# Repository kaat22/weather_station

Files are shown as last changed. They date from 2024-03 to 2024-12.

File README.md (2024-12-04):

# Weather Station

## Introduction
The purpose of this project was to make a weather station (Figure 1), which will read and send the measurements to a server.

kuva Figure 1: Weather station

## Objectives
The basic aim was to make a functional weather station, which would send the data to a server, that could then be read from a computer.
Our secondary aim was to make the weather station rechargeable, using a LiFePO4 battery (Figure 2). Using a battery to power the station allows it to work without being connected to a computer or a power outlet.

kuva Figure 2: LiFePO4 battery

## Methods
The microcontroller we used in the project was ESP32-WROOM-32E (Figure 3). The microcontroller has built-in Wi-Fi that allows it to send the data to a server. There are two sensors which measure the temperature, humidity and air pressure.

kuva Figure 3: ESP32-WROOM-32E

## Results
We achieved our primary goal of gathering and transferring data (via Wi-Fi) from the station's sensors to a server, wherefrom it can be viewed through a web browser. We also partially achieved our secondary goal of powering the device with a rechargeable battery, however due to an error in the pcb design phase we were unable to get the recharging feature of the charging circuit functional.

## Refrences
ESP-32WROOM-32E datasheet Source:

esp32-wroom-32e_esp32-wroom-32ue_datasheet_en.pdf ([espressif.com](https://www.espressif.com/en/support/documents/technical-documents))

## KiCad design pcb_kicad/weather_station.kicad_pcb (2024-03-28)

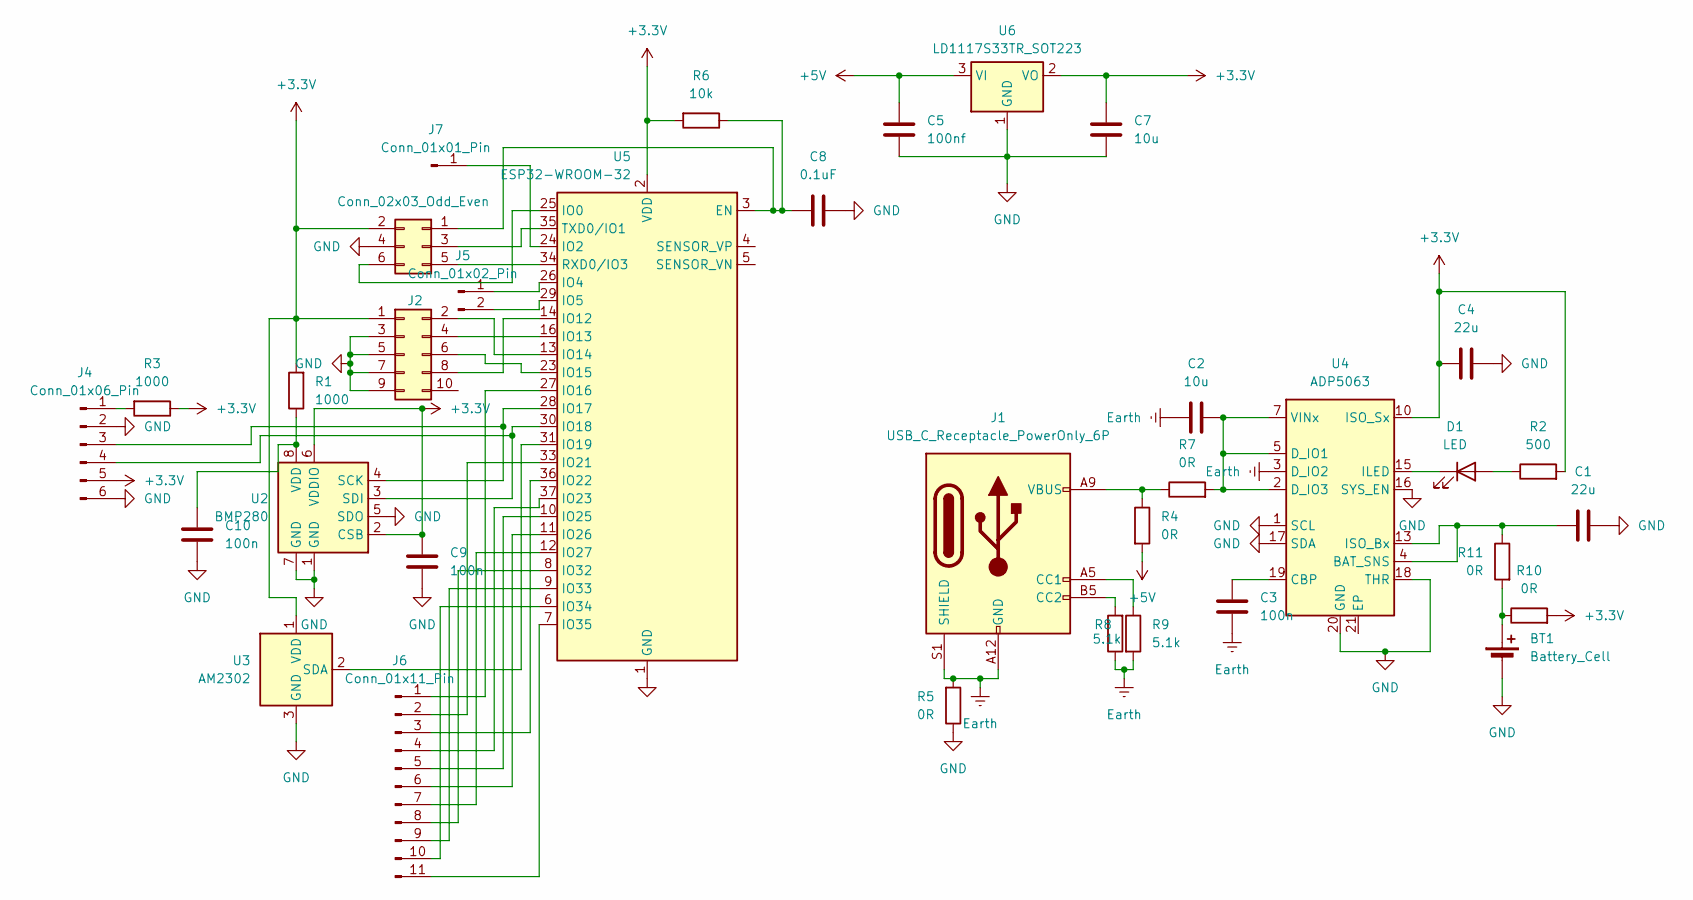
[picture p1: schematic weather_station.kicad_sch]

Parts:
BT1: Battery_Cell; BatteryHolder_Keystone_1042_1x18650
C1, C4: 22u; C_0603_1608Metric_Pad1.08x0.95mm_HandSolder
C2, C7: 10u; C_0603_1608Metric_Pad1.08x0.95mm_HandSolder
C3, C9, C10: 100n; C_0603_1608Metric_Pad1.08x0.95mm_HandSolder
C5: 100nf; C_0603_1608Metric_Pad1.08x0.95mm_HandSolder
C8: 0.1uF; C_0603_1608Metric_Pad1.08x0.95mm_HandSolder
D1: LED; LED_0603_1608Metric_Pad1.05x0.95mm_HandSolder
J1: USB_C_Receptacle_PowerOnly_6P; USB_C_Receptacle_GCT_USB4125-xx-x-0190_6P_TopMnt_Horizontal
J2: Conn_02x05_Odd_Even; IDC-Header_2x05_P2.54mm_Vertical
J3: Conn_02x03_Odd_Even; IDC-Header_2x03_P2.54mm_Vertical
J4: Conn_01x06_Pin; PinHeader_1x06_P2.54mm_Vertical
J5: Conn_01x02_Pin; TestPoint_2Pads_Pitch2.54mm_Drill0.8mm
J6: Conn_01x11_Pin; PinHeader_1x11_P2.54mm_Vertical
J7: Conn_01x01_Pin; PinSocket_1x01_P2.54mm_Vertical
R1, R3: 1000; R_0603_1608Metric_Pad0.98x0.95mm_HandSolder
R2: 500; R_0603_1608Metric_Pad0.98x0.95mm_HandSolder
R4, R5, R7, R10, R11: 0R; R_0603_1608Metric_Pad0.98x0.95mm_HandSolder
R6: 10k; R_0603_1608Metric_Pad0.98x0.95mm_HandSolder
R8, R9: 5.1k; R_0603_1608Metric_Pad0.98x0.95mm_HandSolder
U2: BMP280; Bosch_LGA-8_2.5x2.5mm_P0.65mm_ClockwisePinNumbering
U3: AM2302; ASAIR_AM2302_P2.54mm_Vertical
U4: ADP5063; QFN-20-1EP_4x4mm_P0.5mm_EP2.5x2.5mm
U5: ESP32-WROOM-32; ESP32-WROOM-32D
U6: LD1117S33TR_SOT223; SOT-223-3_TabPin2

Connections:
+3.3V: C4.1, C7.2, C9.1, J2.1, J3.2, J4.5, R1.2, R2.2, R3.1, R6.2, R10.2, U2.2 (CSB), U2.6 (VDDIO), U3.1 (VDD), U4.9 (ISO_Sx), U4.10 (ISO_Sx), U4.11 (ISO_Sx), U5.2 (VDD), U6.2 (VO)
+5V: C5.1, R4.2, U6.3 (VI)
Earth: C2.2, C3.2, J1.A12 (GND), J1.B12 (GND), J1.S1 (SHIELD), R5.2, R8.1, R9.2, U4.3 (D_IO2)
GND: BT1.2 (-), C1.2, C4.2, C5.2, C7.1, C8.2, C9.2, C10.2, J2.3, J2.5, J2.7, J2.9, J3.4, J4.2, J4.6, R5.1, U2.1 (GND), U2.5 (SDO), U2.7 (GND), U3.3 (GND), U3.4 (GND), U4.1 (SCL), U4.16 (SYS_EN), U4.17 (SDA), U4.18 (THR), U4.20 (GND), U5.1 (GND), U5.15 (GND), U5.38 (GND), U5.39 (GND), U6.1 (GND)
unnamed: BT1.1 (+), R10.1, R11.2
unnamed: D1.2 (A), R2.1
unnamed: D1.1 (K), U4.15 (ILED)
unnamed: J1.A5 (CC1), R9.1
unnamed: J1.B5 (CC2), R8.2
unnamed: J1.A9 (VBUS), J1.B9 (VBUS), R4.1, R7.1
unnamed: J2.2, U5.13 (IO14)
unnamed: J2.4, U5.16 (IO13)
unnamed: J2.6, U5.23 (IO15)
unnamed: J2.8, U5.14 (IO12)
unnamed: C8.1, J3.1, R6.1, U5.3 (EN)
unnamed: J3.3, U5.35 (TXD0/IO1)
unnamed: J3.5, U5.34 (RXD0/IO3)
unnamed: J3.6, U5.25 (IO0)
unnamed: J4.1, R3.2
unnamed: J4.3, U2.4 (SCK), U5.28 (IO17)
unnamed: J4.4, U2.3 (SDI), U5.30 (IO18)
unnamed: J5.1, U5.26 (IO4)
unnamed: J5.2, U5.29 (IO5)
unnamed: J6.1, U5.27 (IO16)
unnamed: J6.2, U5.33 (IO21)
unnamed: J6.3, U5.36 (IO22)
unnamed: J6.4, U5.37 (IO23)
unnamed: J6.5, U5.10 (IO25)
unnamed: J6.6, U5.11 (IO26)
unnamed: J6.7, U5.12 (IO27)
unnamed: J6.8, U5.8 (IO32)
unnamed: J6.9, U5.9 (IO33)
unnamed: J6.10, U5.6 (IO34)
unnamed: J6.11, U5.7 (IO35)
unnamed: J7.1, U5.24 (IO2)
unnamed: C10.1, R1.1, U2.8 (VDD)
unnamed: U3.2 (SDA), U5.31 (IO19)
unnamed: C1.1, R11.1, U4.4 (BAT_SNS), U4.12 (ISO_Bx), U4.13 (ISO_Bx), U4.14 (ISO_Bx)
unnamed: C3.1, U4.19 (CBP)
unnamed: C2.1, R7.2, U4.2 (D_IO3), U4.5 (D_IO1), U4.6 (VINx), U4.7 (VINx), U4.8 (VINx)

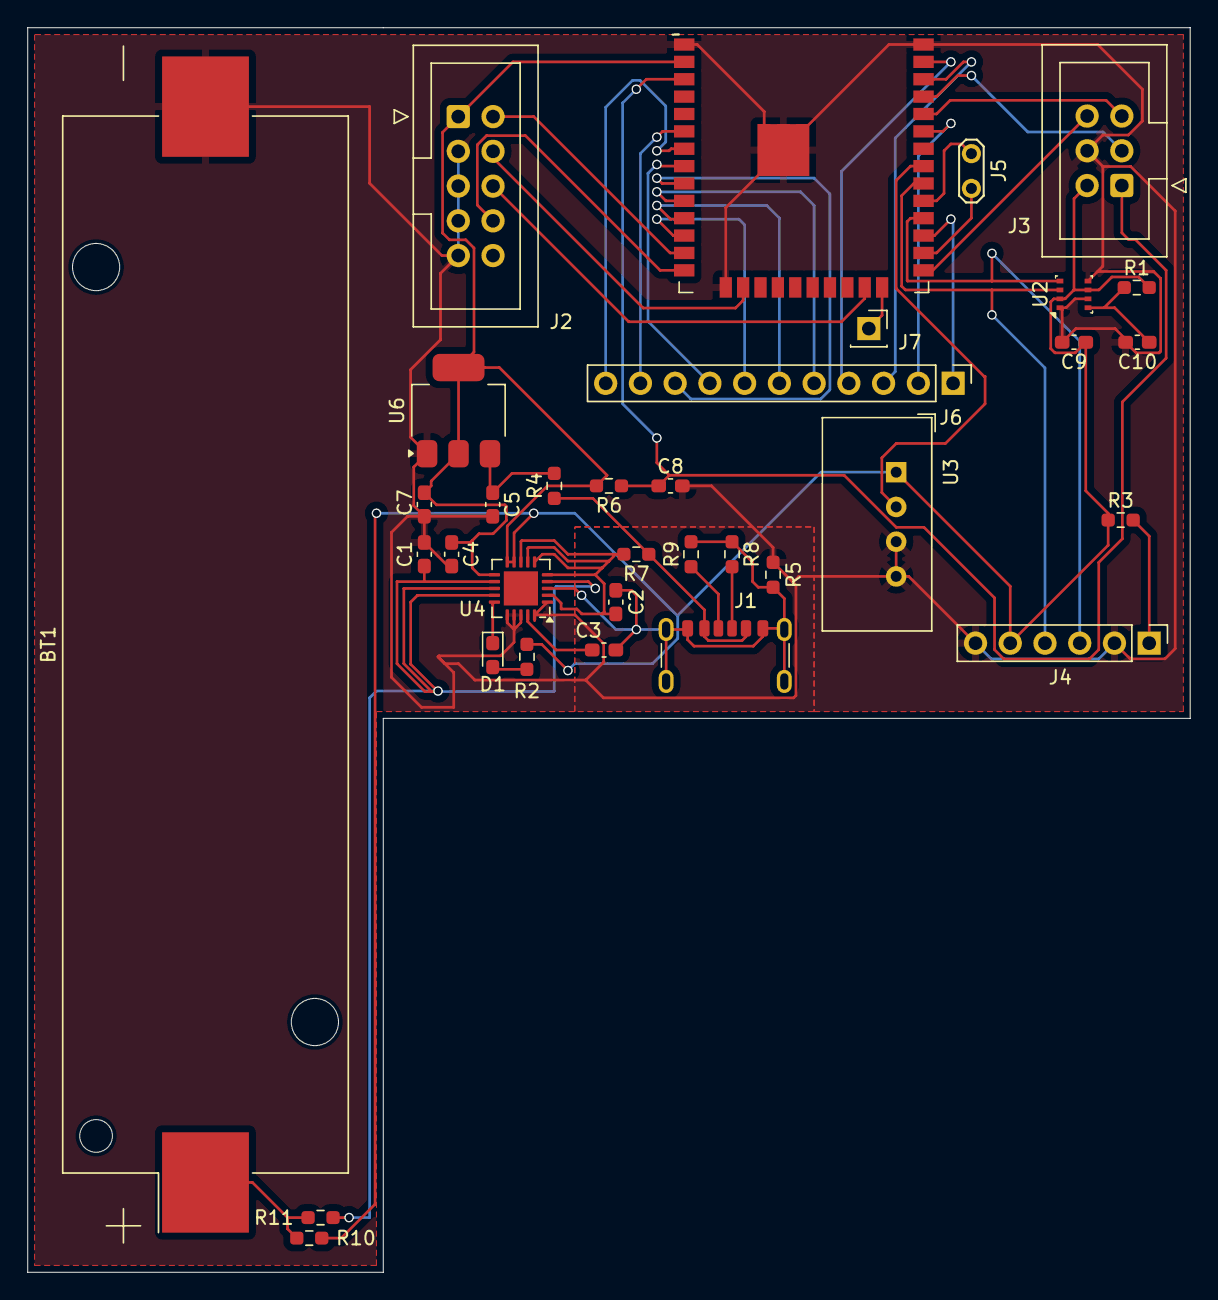
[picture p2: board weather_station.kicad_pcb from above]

Board: 2 copper layers, 85.0 x 91.0 mm, 34 parts (0 on the bottom side), 40 nets.

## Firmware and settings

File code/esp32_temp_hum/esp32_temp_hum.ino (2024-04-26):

#include <WiFi.h>
#include <HTTPClient.h>
#include <DHT.h>
#include <Wire.h>
#include <Adafruit_BMP280.h>
#include "credentials.h"

#define DHTPIN 19
#define I2C_SDA 18
#define I2C_SCL 17

TwoWire I2CBMP = TwoWire(0);
DHT dht22(DHTPIN, DHT22);
Adafruit_BMP280 bmp(&I2CBMP);

String URL = "http://" + IP + "/weather/postdata.php";

int temp = 0;
int hum = 0;
int temp_bmp = 0;
int pres = 0;

void setup() {
    Serial.begin(115200);
    I2CBMP.begin(I2C_SDA, I2C_SCL, 100000);
    bmp.begin(0x77);
    dht22.begin();
    WiFiConnect();
}

void loop() {
    temp = dht22.readHumidity();
    hum = dht22.readTemperature();
    temp_bmp = bmp.readTemperature();
    pres = bmp.readPressure();
    Serial.println(temp_bmp);
    Serial.println(pres);
    sendPostRequest();
    delay(10000);
}

void WiFiConnect() {
    WiFi.mode(WIFI_STA);
    WiFi.begin(ssid, password);
    
    while (WiFi.status() != WL_CONNECTED) {
        delay(300);
        Serial.print(".");
    }

    Serial.print("\nConnected to: ");
    Serial.println(ssid);
    Serial.print("IP address: ");
    Serial.println(WiFi.localIP());
}


void sendPostRequest() {
    String postdata = "temp=" + String(temp) + "&temp_bmp=" + String(temp_bmp) + "&hum=" + String(hum) + "&pres=" + String(pres);
    HTTPClient http;
    http.begin(URL);

    http.addHeader("Content-Type", "application/x-www-form-urlencoded");
    int httpcode = http.POST(postdata);
    String response = http.getString();

    Serial.print("URL: ");
    Serial.println(URL);
    Serial.print("Data: ");
    Serial.println(postdata);
    Serial.print("httpcode: ");
    Serial.println(httpcode);
    Serial.print("response: ");
    Serial.println(response);
}

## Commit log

2024-03-21 kicad tiedostot
    [weather_station.kicad_pcb, weather_station.kicad_sch]
2024-03-21 Added initial circuit diagram
    [weather_station.kicad_sch]
2024-03-25 changed esp32 soc to the esp32wroom
    [weather_station.kicad_sch]
2024-03-26 added voltage regulator circuit for BMP280 VDDIO and and an alternative connection point for BMP280 module
    [weather_station.kicad_sch]
2024-03-27 added full pcb schematic
    [weather_station.kicad_pcb, weather_station.kicad_sch]
2024-03-27 added ground fills
    [weather_station.kicad_pcb]
2024-03-28 added 0 ohm resistors for battery only mode, out pins for all unused pins from esp 32, opened blind vias and removed unsupported vias and silkscreen drawings from esp32 blueprint
    [weather_station.kicad_pcb, weather_station.kicad_sch]
